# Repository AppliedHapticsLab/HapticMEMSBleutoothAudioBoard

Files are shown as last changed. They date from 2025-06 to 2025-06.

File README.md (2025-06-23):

# Bluetooth Audio Boards Project





BM83 BluetoothモジュールとCS4344 DACを使用してMEMSを駆動するデバイスです。

*メイン基板の完成例*
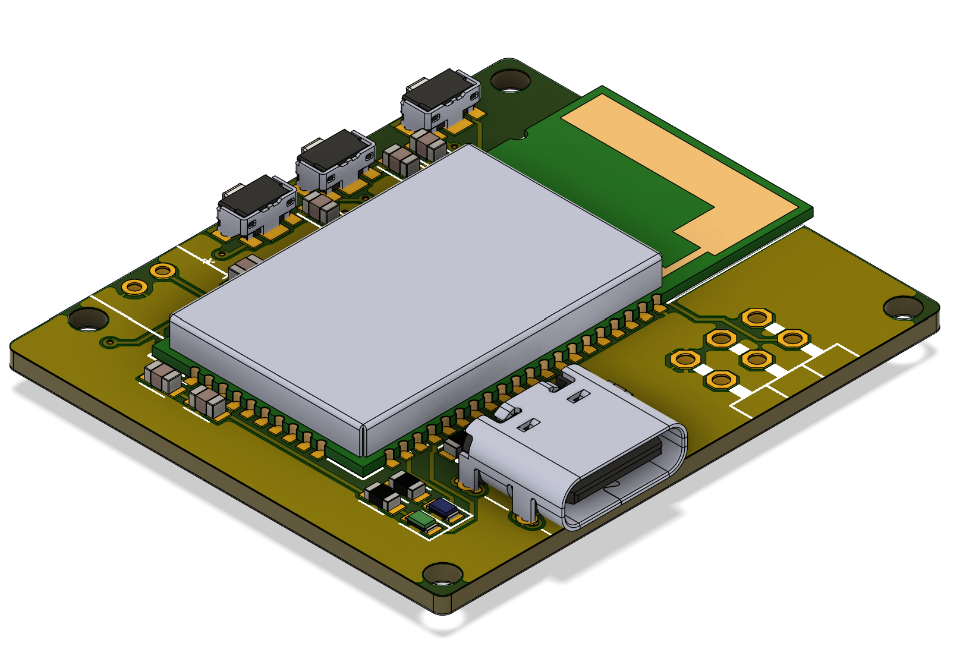
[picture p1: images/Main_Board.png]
Main Board


*メインに重ねる基板の完成例*
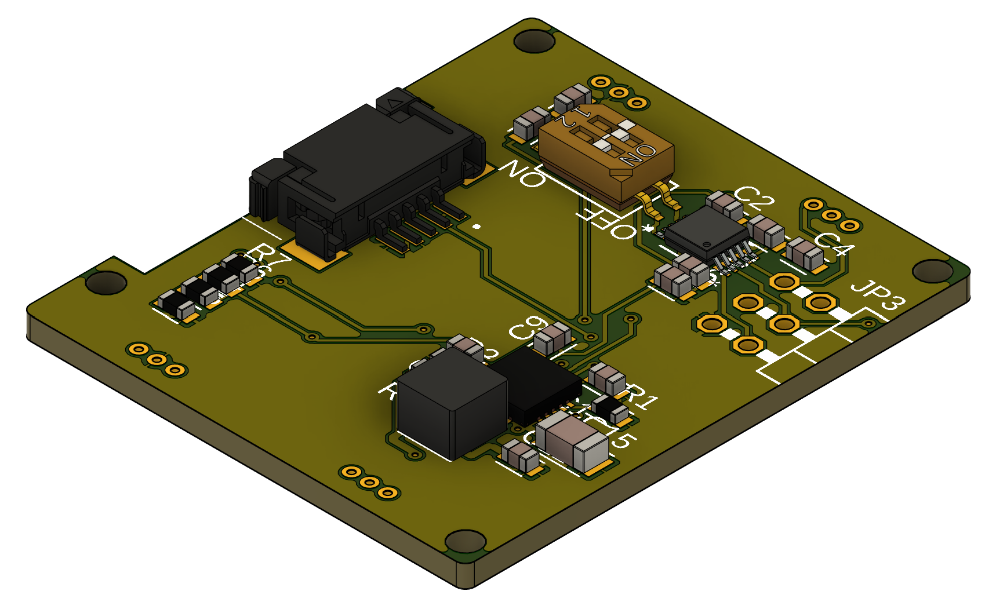
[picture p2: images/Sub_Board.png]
Main Board


*サブ基板の完成例*
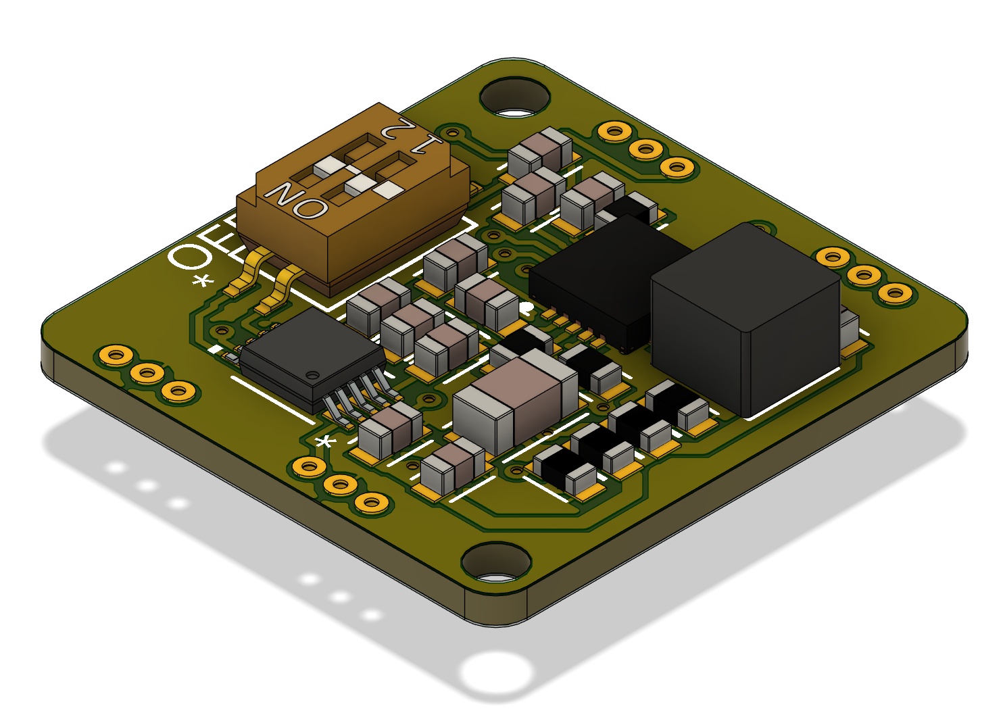
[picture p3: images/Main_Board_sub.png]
Main Board


## 目次

- [プロジェクト概要](#プロジェクト概要)
- [基板構成](#基板構成)
- [技術仕様](#技術仕様)
- [主要機能](#主要機能)
- [使用方法](#使用方法)
- [開発環境](#開発環境)
- [ファイル構成](#ファイル構成)
- [ライセンス](#ライセンス)

## プロジェクト概要

このプロジェクトは、Bluetooth音声受信と高品質DAC出力を組み合わせた音声システムです。メイン基板で受信したBluetooth音声をI2S経由で各サブ基板に分配し、高電圧音声信号として出力します。

## 基板構成

### 1. Main_Board（メイン基板）

メインコントローラとして機能する基板です。

**主要機能:**
- **Bluetooth音声受信**: BM83モジュールによるワイヤレス音声受信
- **I2S信号分配**: Main_Board_sub、Sub_Board上のCS4344 DACへのデータ送信
- **電源管理**: USB充電機能付きLiPoバッテリーシステム
- **ユーザーインターフェース**: 音声停止・再生操作ボタン
- **高電圧音声出力**: DRV2700 + CS4344による高電圧音声信号生成

**主要IC:**
- BM83: Bluetoothオーディオモジュール
- CS4344: 24-bit/192kHz ステレオDAC
- DRV2700: 高電圧アンプドライバー

**電源仕様:**
- LiPoバッテリー駆動
- USB充電対応
- 昇圧回路搭載（5V供給）

### 2. Main_Board_sub（メインサブ基板）

メイン基板と同サイズの基板で、DAC機能を担当します。

**特徴:**
- CS4344 DAC搭載
- Main_Boardと同一フォームファクター
- I2S信号受信による音声出力

### 3. Sub_Board（サブ基板）

コンパクトサイズの基板で、DAC機能を担当します。

**特徴:**
- CS4344 DAC搭載
- 小型フォームファクター
- I2S信号受信による音声出力
- 省スペース設置に最適

## システム構成

```
Bluetooth Device
    ↓ Bluetooth Audio
Main_Board (BM83)
    ↓ I2S Signal Distribution
    ├─→ Main_Board_sub (CS4344 DAC) → Audio Output
    └─→ Sub_Board (CS4344 DAC) → Audio Output
```

## 技術仕様

| 項目 | 仕様 |
|---|---|
| Bluetoothチップ | BM83 |
| DAC | CS4344 (24-bit/192kHz) |
| アンプドライバー | DRV2700 |
| 電源 | LiPoバッテリー + USB充電 |
| 音声インターフェース | I2S |
| 昇圧回路 | 5V出力 |

## 主要機能

### 音声処理
- Bluetooth A2DPプロファイル対応
- 高品質24-bit/192kHz DAC出力
- 低レイテンシー音声伝送
- 高電圧音声信号生成

### 電源管理
- LiPoバッテリー駆動
- USB充電システム
- 効率的な昇圧回路
- 低消費電力設計

### ユーザーインターフェース
- 再生/停止ボタン
- シンプルな操作性
- 直感的なコントロール

## 使用方法

### 初期設定
```bash
# リポジトリをクローン
git clone https://github.com/yourusername/bluetooth-audio-boards.git
cd bluetooth-audio-boards
```

- 以下のURLを参考にBM83用のツールソフトをダウンロード・設定する
- URL：https://www.zep.co.jp/kzenyouji/article/z-bm83-da2/

### 基本操作
1. **電源投入**: LiPoバッテリー接続 or USB給電
2. **ペアリング**: 電源投入時に自動的にペアリングモード
3. **音声再生**: Bluetoothデバイスから音声を送信
4. **コントロール**: 基板上のボタンで再生/停止

## 開発環境

### 必要なツール
- PCB設計ソフトウェア
- はんだ付け用具
- 測定器具（オシロスコープ、マルチメーター）

### 推奨開発環境
- Eagle CAD または Fusion360
- 温度制御はんだごて
- デジタルマルチメーター

## ファイル構成

```
/
├── 1.Main_Board/                 # メイン基板設計ファイル
│   ├── Main_Board.brd         
│   ├── Main_Board.sch
│   └── Main_Board_3D.stl
├── 2.Main_Board_sub/            # メインサブ基板設計ファイル
│   ├── Main_Board_sub.brd         
│   ├── Main_Board_sub.sch
│   └── Main_Board_sub_3D.stl
├── 3.Sub_Board/                 # サブ基板設計ファイル
│   ├── Sub_Board.brd         
│   ├── Sub_Board.sch
│   └── Sub_Board_3D.stl
├── images/                      # プロジェクト画像
├── LICENSE                      # ライセンスファイル
├── OptionFile.hex　　　　　　　　# BM83用の設定ファイル
└── README.md                   # このファイル
```

## 謝辞
参考にさせていただいたサイトになります．
- https://www.zep.co.jp/kzenyouji/article/z-bm83-da2/
- https://cotechworks.ltt.jp/2024/08/15/post-1609/

## ライセンス

このプロジェクトは MIT ライセンスの下で公開されています。詳細は [LICENSE](LICENSE) ファイルを参照してください。

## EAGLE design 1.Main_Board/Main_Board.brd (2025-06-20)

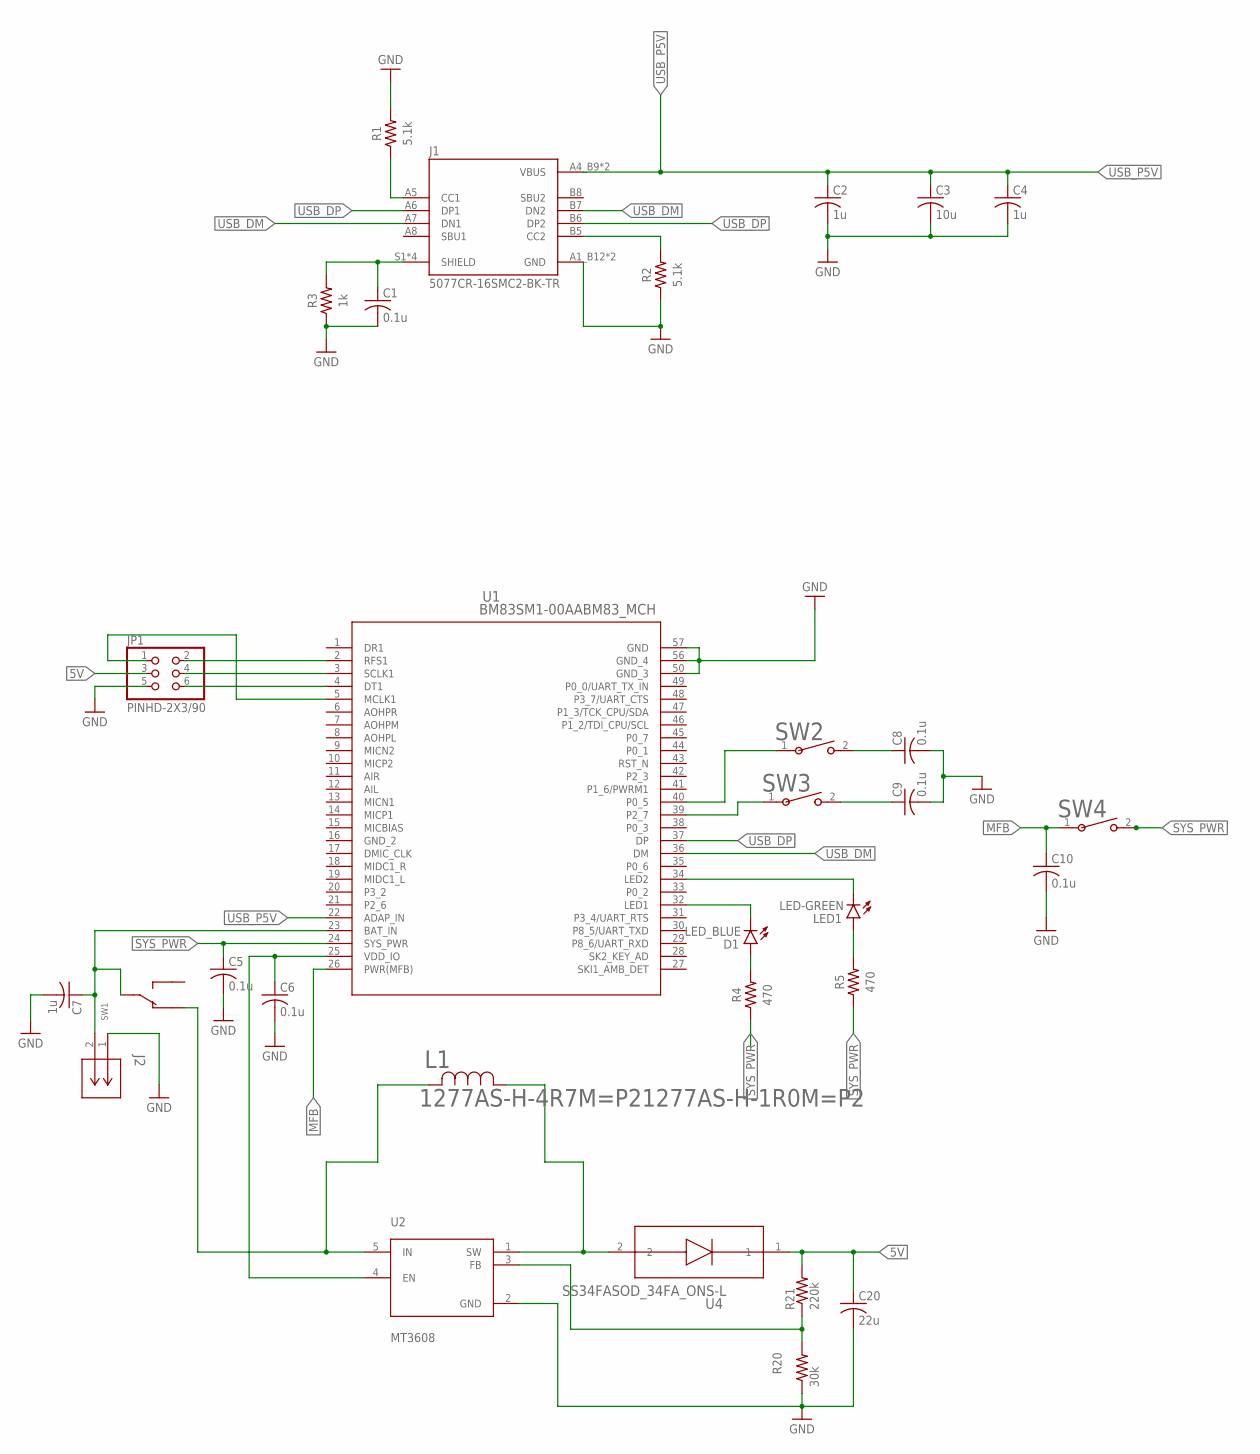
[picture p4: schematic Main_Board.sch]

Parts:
C1, C5, C6, C8, C9, C10: 0.1u; CAPC1608X85
C2, C4, C7: 1u; CAPC1608X85
C3: 10u; CAPC1608X85
C20: 22u; CAPC3216X135
D1: LED_BLUE; LEDC1608X39N_B
J1: 5077CR-16SMC2-BK-TR; NELTRON_5077CR-16SMC2-BK-TR
J2: S2B-PH-K-S(LF)(SN); CONN_S2B-PH-K-S_JST
JP1: PINHD-2X3/90; 2X03/90
L1: 1277AS-H-4R7M=P21277AS-H-1R0M=P2; 1277AS-H-1R0M=P2
LED1: LED-GREEN; LEDC1608X39N_G
R1, R2: 5.1k; RESC1608X60
R3: 1k; RESC1608X60
R4, R5: 470; RESC1608X60
R20: 30k; RESC1608X60
R21: 220k; RESC1608X60
SW1: MMS124
SW2, SW3, SW4: EVP-AKE31ASW_EVP-AKE31A_PAN; SW_EVP-AKE31A_PAN
U1: BM83SM1-00AABM83_MCH; BM83_MCH
U2: MT3608; SOT95P280X145-6N
U4: SS34FASOD_34FA_ONS-L; SOD_34FA_ONS-L

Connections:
5V: C20.1, JP1.3, R21.2, U4.1
GND: C1.2, C2.2, C3.2, C4.2, C5.2, C6.2, C7.2, C8.2, C9.2, C10.2, C20.2, J1.A1_B12 (GND), J1.B1_A12 (GND), J2.1, JP1.5, R1.2, R2.1, R3.1, R20.1, U1.50 (GND_3), U1.56 (GND_4), U1.57 (GND), U2.2 (GND)
MFB: C10.1, SW4.1, U1.26 (PWR(MFB))
MICBIAS: U1.15 (MICBIAS)
unnamed: J1.A5 (CC1), R1.1
unnamed: J1.B5 (CC2), R2.2
unnamed: C1.1, J1.S1 (SHIELD), J1.S2 (SHIELD), J1.S3 (SHIELD), J1.S4 (SHIELD), R3.2
unnamed: L1.1, U2.1 (SW), U4.2
unnamed: JP1.2, U1.2 (RFS1)
unnamed: JP1.4, U1.3 (SCLK1)
unnamed: JP1.6, U1.4 (DT1)
unnamed: JP1.1, U1.5 (MCLK1)
unnamed: C7.1, J2.2, SW1.3 (2), U1.23 (BAT_IN)
unnamed: SW2.1, U1.40 (P0_5)
unnamed: SW3.1, U1.39 (P2_7)
unnamed: C8.1, SW2.2
unnamed: C9.1, SW3.2
unnamed: R20.2, R21.1, U2.3 (FB)
unnamed: L1.2, SW1.1, U2.5 (IN)
unnamed: C6.1, U1.25 (VDD_IO), U2.4 (EN)
unnamed: D1.1 (C), U1.32 (LED1)
unnamed: D1.2 (A), R4.2
unnamed: LED1.1 (C), U1.34 (LED2)
unnamed: LED1.2 (A), R5.2
SYS_PWR: C5.1, R4.1, R5.1, SW4.2, U1.24 (SYS_PWR)
USB_DM: J1.A7 (DN1), J1.B7 (DN2), U1.36 (DM)
USB_DP: J1.A6 (DP1), J1.B6 (DP2), U1.37 (DP)
USB_P5V: C2.1, C3.1, C4.1, J1.A4_B9 (VBUS), J1.B4_A9 (VBUS), U1.22 (ADAP_IN)

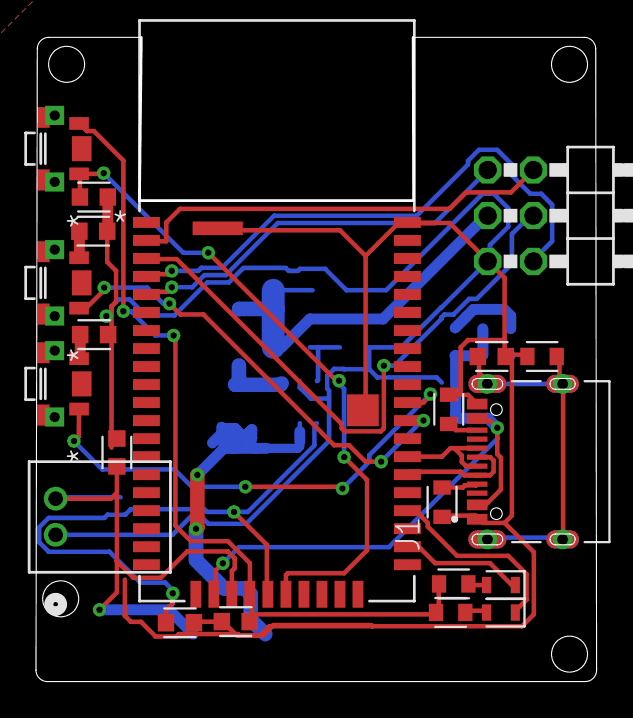
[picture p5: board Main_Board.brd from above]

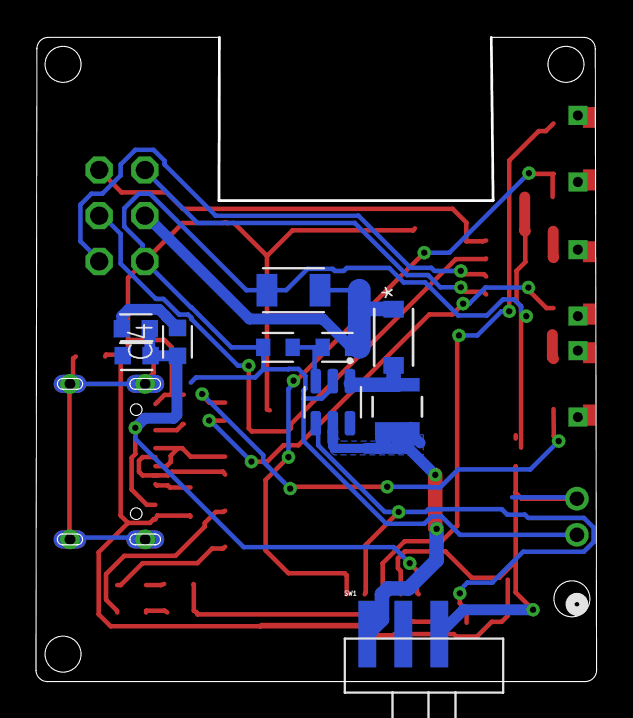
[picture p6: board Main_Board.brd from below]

Board: 2 copper layers, 31.1 x 35.8 mm, 31 parts (10 on the bottom side), 27 nets.

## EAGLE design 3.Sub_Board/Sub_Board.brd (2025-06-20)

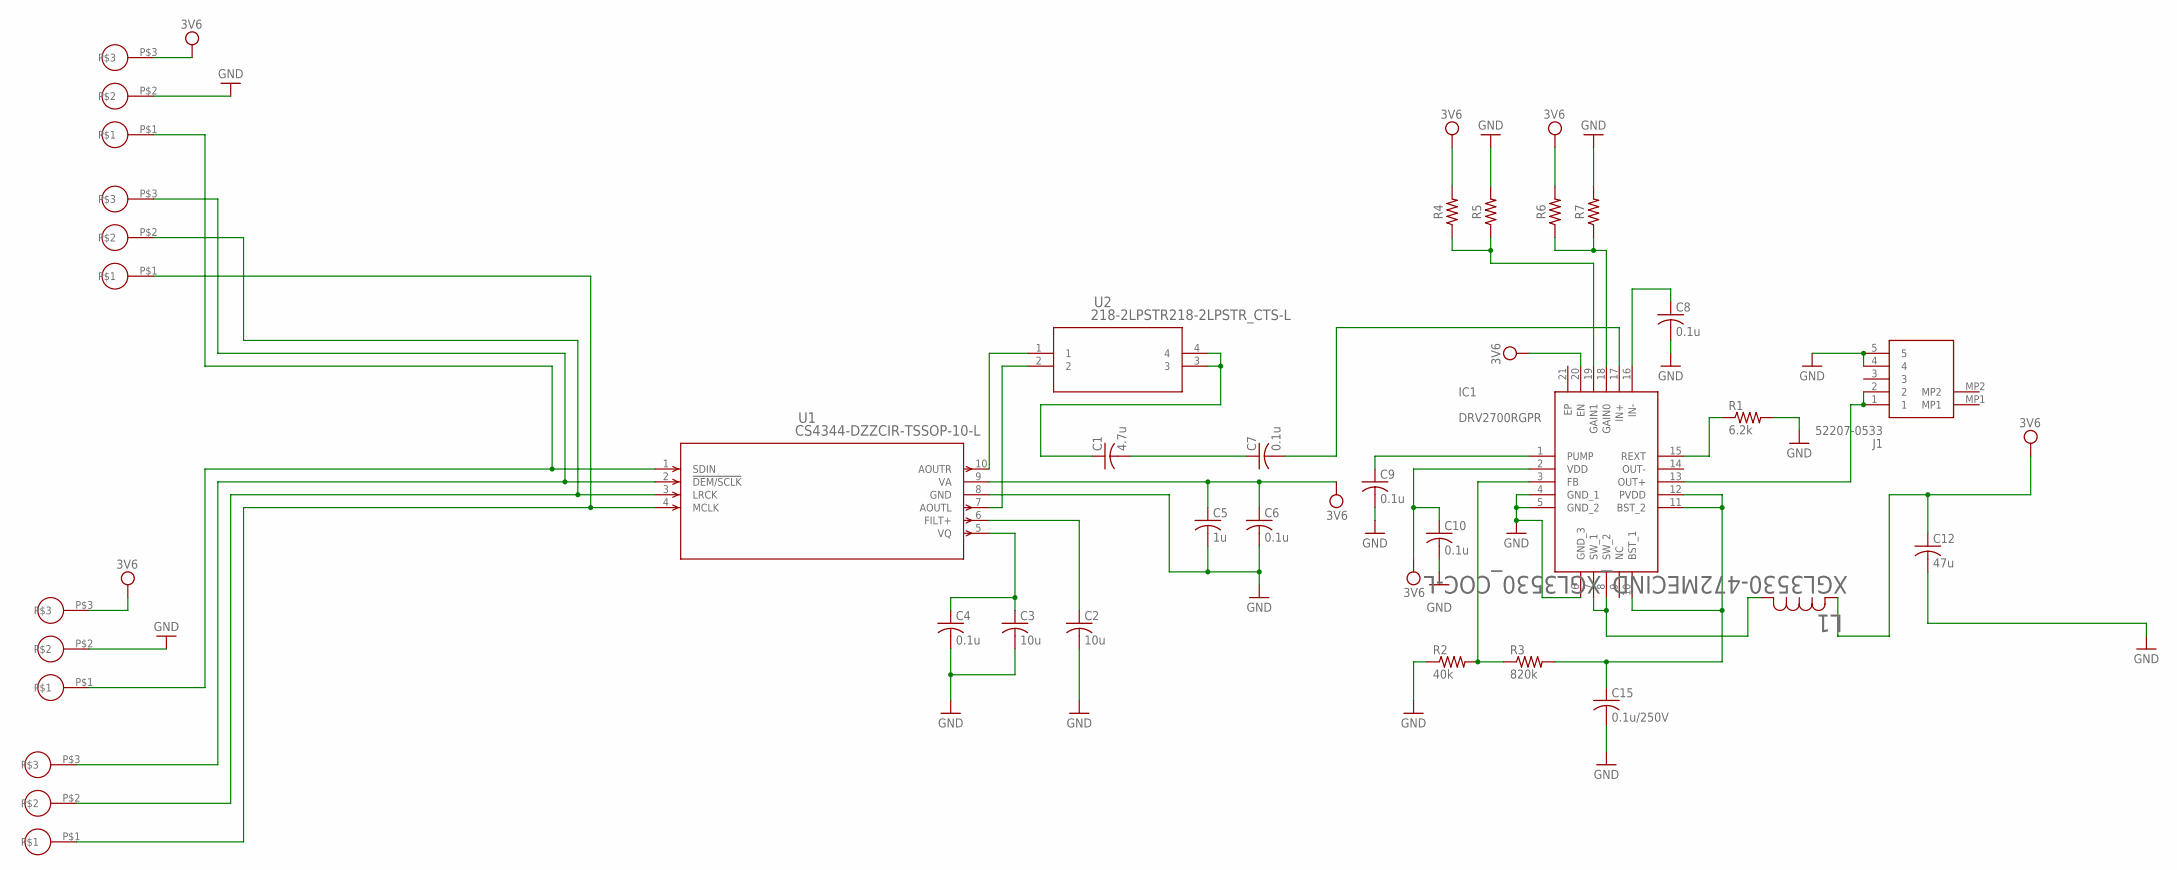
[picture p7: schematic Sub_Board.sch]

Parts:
C1: 4.7u; CAPC1608X85
C2, C3: 10u; CAPC1608X85
C4, C6, C7, C8, C9, C10: 0.1u; CAPC1608X85
C5: 1u; CAPC1608X85
C12: 47u; CAPC1608X85
C15: 0.1u/250V; CAPC3216X135
IC1: DRV2700RGPR; QFN50P400X400X100-21N
J1: 52207-0533; 522070533
L1: XGL3530-472MECIND_XGL3530_COC-L; IND_XGL3530_COC-L
R1: 6.2k; RESC1608X60
R2: 40k; RESC1608X60
R3: 820k; RESC1608X60
R4, R5, R6, R7: R-US_CHIP-0603(1608-METRIC); RESC1608X60
U1: CS4344-DZZCIR-TSSOP-10-L; CIR-TSSOP-10-L
U2: 218-2LPSTR218-2LPSTR_CTS-L; 218-2LPSTR_CTS-L
U$1, U$2, U$3, U$4: CONECTOR_MEM

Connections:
3V6: C5.1, C6.1, C10.1, C12.1, IC1.2 (VDD), IC1.20 (EN), L1.2, R4.2, R6.2, U1.9 (VA), U$1.P$3, U$3.P$3
GND: C2.2, C3.2, C4.2, C5.2, C6.2, C8.2, C9.2, C10.2, C12.2, C15.2, IC1.4 (GND_1), IC1.5 (GND_2), IC1.6 (GND_3), J1.4, J1.5, R1.2, R2.1, R5.2, R7.2, U1.8 (GND), U$1.P$2, U$3.P$2
unnamed: C1.1, U2.3, U2.4
unnamed: C1.2, C7.1
unnamed: C7.2, IC1.17 (IN+)
unnamed: C8.1, IC1.16 (IN-)
unnamed: C2.1, U1.6 (FILT+)
unnamed: C3.1, C4.1, U1.5 (VQ)
unnamed: U1.4 (MCLK), U$2.P$1, U$4.P$1
unnamed: C9.1, IC1.1 (PUMP)
unnamed: IC1.3 (FB), R2.2, R3.1
unnamed: C15.1, IC1.10 (BST_1), IC1.11 (BST_2), IC1.12 (PVDD), R3.2
unnamed: IC1.15 (REXT), R1.1
unnamed: IC1.7 (SW_1), IC1.8 (SW_2), L1.1
unnamed: IC1.13 (OUT+), J1.1, J1.2
unnamed: IC1.18 (GAIN0), R6.1, R7.1
unnamed: IC1.19 (GAIN1), R4.1, R5.1
unnamed: U1.10 (AOUTR), U2.1
unnamed: U1.7 (AOUTL), U2.2
unnamed: U1.3 (LRCK), U$2.P$2, U$4.P$2
unnamed: U1.2 (!DEM/SCLK), U$2.P$3, U$4.P$3
unnamed: U1.1 (SDIN), U$1.P$1, U$3.P$1

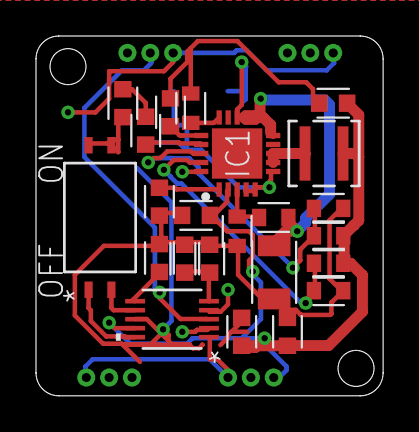
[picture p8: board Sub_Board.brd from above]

Board: 4 copper layers, 19.3 x 20.0 mm, 28 parts (1 on the bottom side), 22 nets.

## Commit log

2025-06-20 基板等のデータを追加しました
    [Main_Board.brd, Main_Board.sch, Main_Board_sub.brd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]
2025-06-20 設定用のファイルを追加しました
2025-06-20 完成型の画像を追加しました

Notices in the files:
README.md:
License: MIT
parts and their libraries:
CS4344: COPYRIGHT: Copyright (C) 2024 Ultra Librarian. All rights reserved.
